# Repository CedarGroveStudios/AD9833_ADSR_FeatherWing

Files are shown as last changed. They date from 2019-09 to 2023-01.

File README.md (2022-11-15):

# MOVED TO: CedarGroveStudios/PCB_AD9833_ADSR_FeatherWing
https://github.com/CedarGroveStudios/PCB_AD9833_ADSR_FeatherWing.git

# This repo will be retired 2022-12-01

# AD9833_ADSR_FeatherWing
### _An amplitude-controlled version of the original AD9833 Waveform Generator FeatherWing_

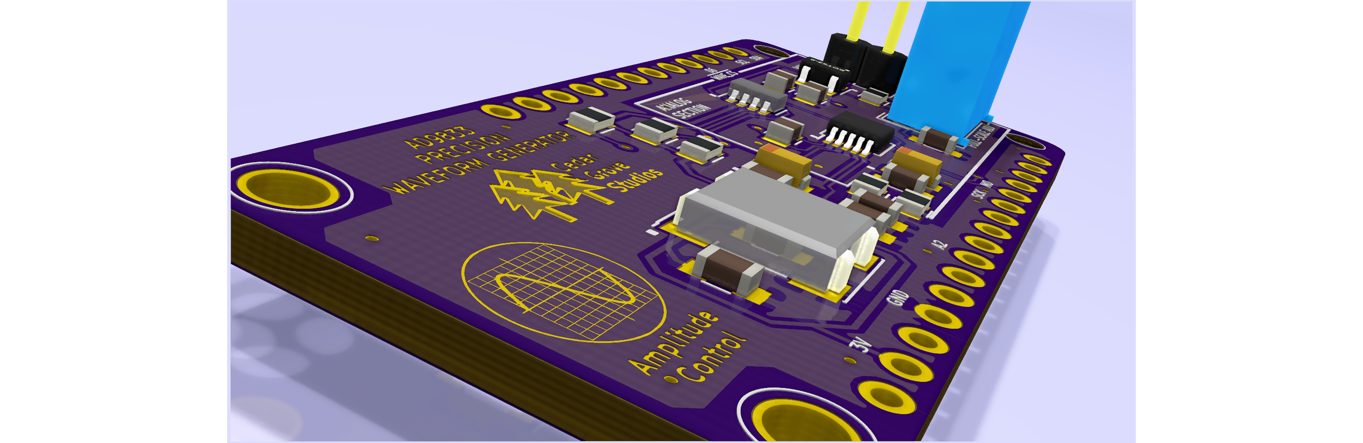
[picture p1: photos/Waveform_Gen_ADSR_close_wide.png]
Image of FeatherWing


## Overview
The AD9833 ADSR FeatherWing project is a software and hardware extension of previous work done on the AD9833 Waveform Generator FeatherWing. The ADSR project adds output amplitude control to simulate the Attack-Decay-Sustain-Release envelope needed to simulate musical instrument sounds.
The AD9833 ADSR FeatherWing is an Adafruit Feather-compatible module. The Waveform Generator portion, controlled by SPI, produces an op-amp buffered sine, triangle, or square wave output with a practical frequency range of 0.5Hz to 100KHz with 0.1Hz resolution. The on-board AD5245 Digital Potentiometer is a 256-step 10K potentiometer controlled by I2C. This PCB version includes enhanced power supply noise reduction and an improved output buffer amplifier with higher gain-bandwidth product.

Example MIDI synthesizer and sweep generator code is provided in the repository (sweep example video: https://youtu.be/O1vMfLoCWzg). 
MIDI synthesizer and sweep generator code was tested with a Feather M4 Express using CircuitPython version 4.1.0 rc-1.

MIDI note input was received by a Classic MIDI Interface FeatherWing from a variety of MIDI sources. See https://github.com/CedarGroveStudios/Classic_MIDI_FeatherWing for details.

OSH Park shared PCB project: https://oshpark.com/shared_projects/nDZsxzWR

## AD5245 Digital Potentiometer for Envelope Control
Unlike using the Feather's internal DAC as a multiplying DAC by applying a waveform to the DAC's reference voltage input, the digital potentiometer doesn't require a reference bias, eliminating the distortion that happens when the DAC's reference voltage is less than about 1v. The digital potentiometer's internal MOSFET switches are biased differently than a DAC, allowing the AD5245 potentiometer to control voltage values between ground and Vcc.

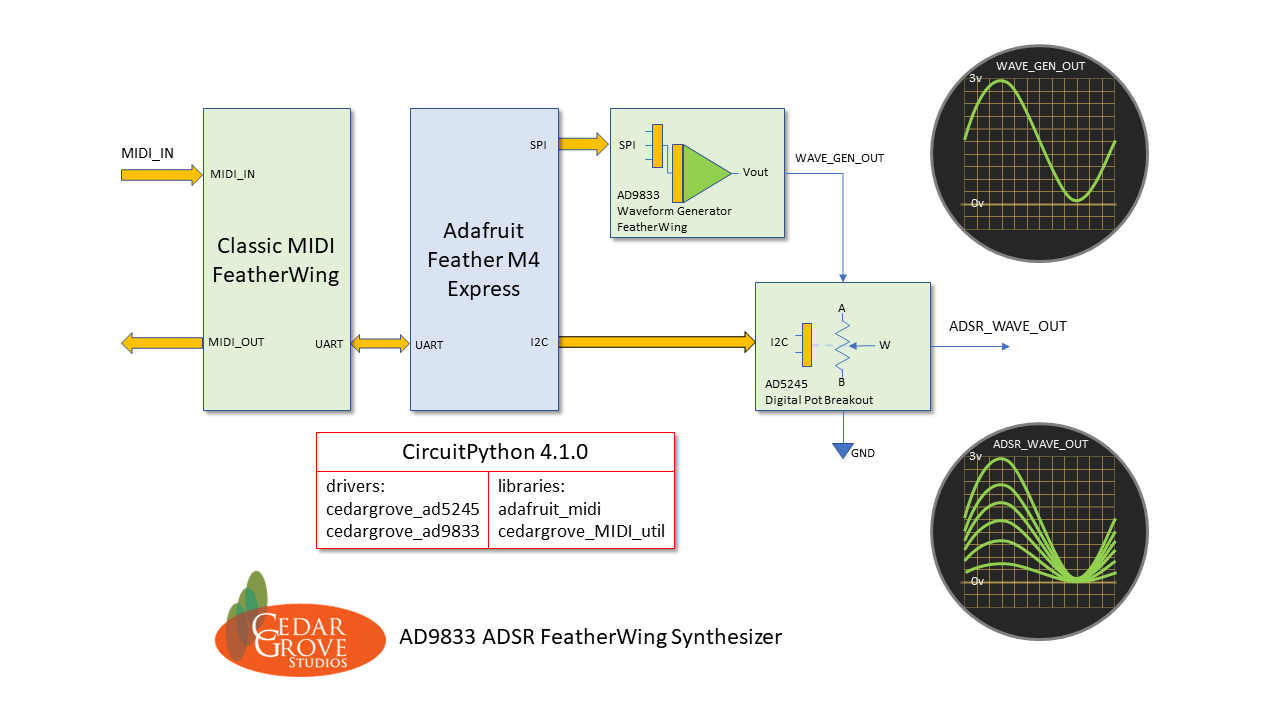
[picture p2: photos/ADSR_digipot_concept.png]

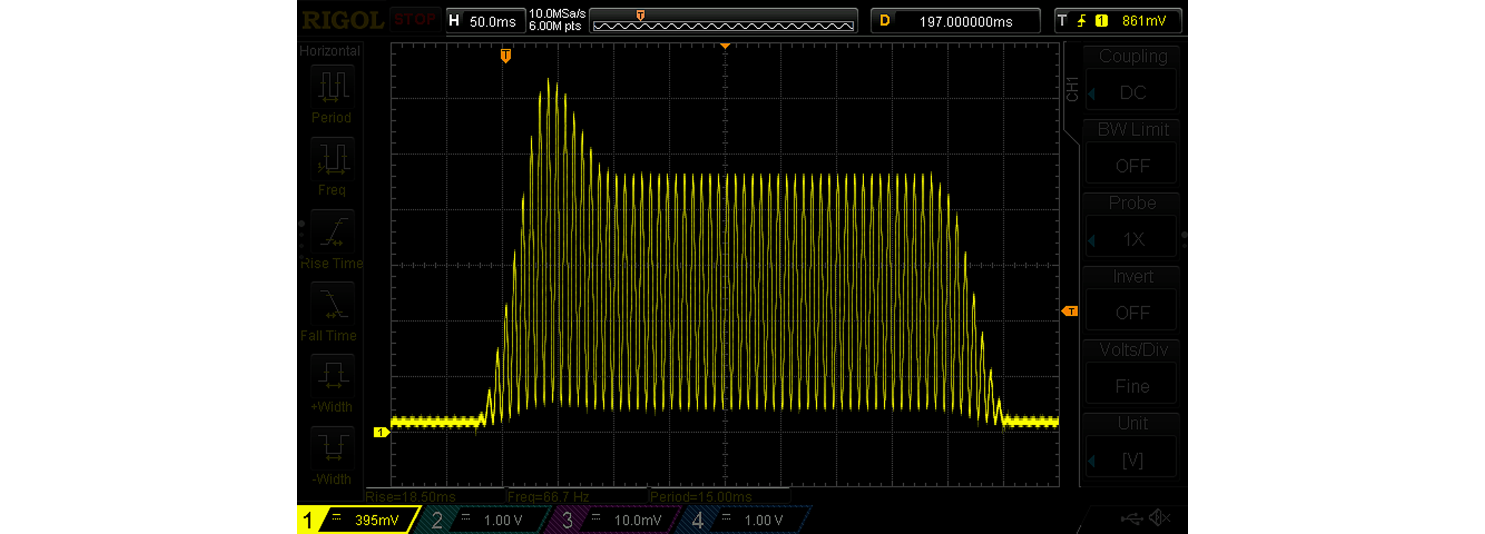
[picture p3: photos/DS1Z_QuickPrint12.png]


The resulting envelope met the original design expectations for distortionless scaling of the waveform's amplitude. The only issue faced was limited I2C data transfer rates during short-duration envelope segments such as shown during the Sustain segment below.

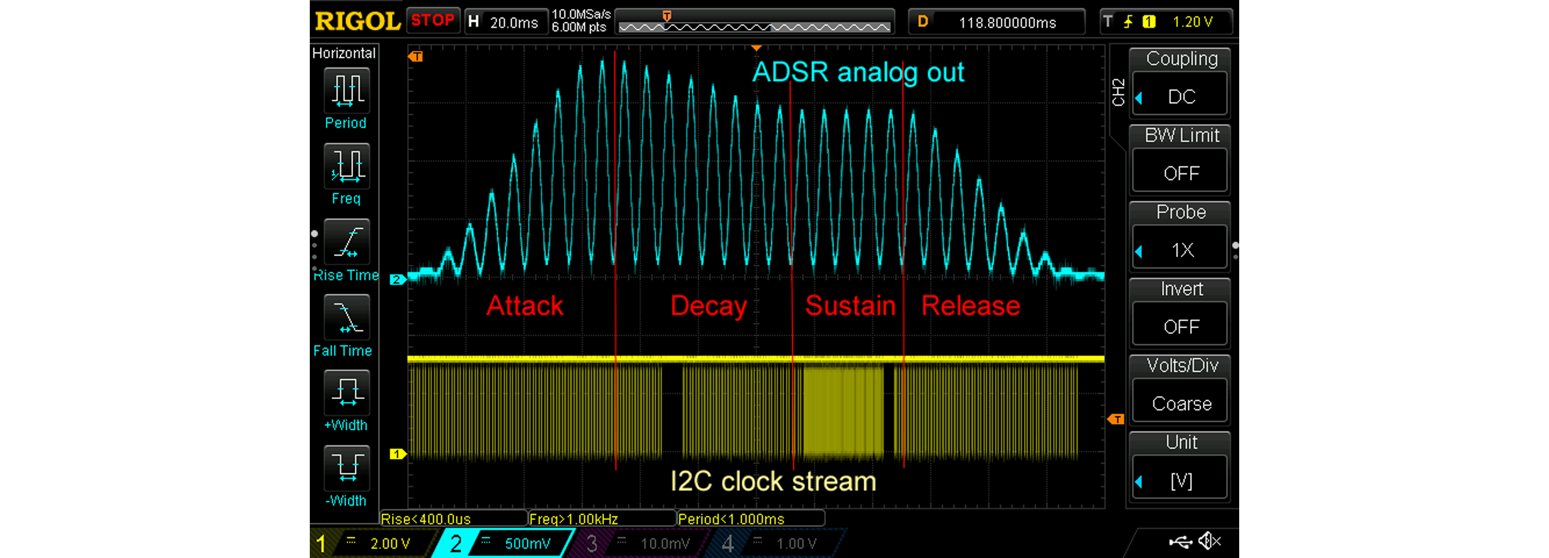
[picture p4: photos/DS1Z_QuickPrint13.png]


The latest version of the envelope segment control algorithm was modified to use a fixed time interval approach rather than a variable time interval based on segment duration. In the newest code, the digital potentiometer updates regularly every 1ms during segment generation, a speed easily accommodated by CircuitPython and the Feather M4 Express.

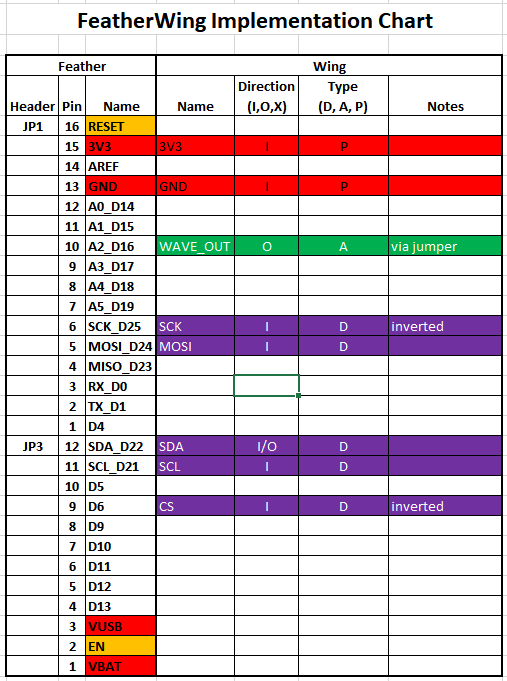
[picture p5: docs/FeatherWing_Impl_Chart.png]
FeatherWing Implementation Chart


## Primary Project Objectives
1)	Generate a smooth ADSR modulated waveform from the AD9833 across the audio spectrum (1Hz to 20KHz).  
2)	Implement with CircuitPython code.
3)  Develop CircuitPython libraries for the AD9833 and AD5245.
4)  Improve output bandwidth.
5)  Reduce power supply noise bleedthrough.
## Deliverables
1)	CircuitPython test, example, and library code
2)  Updated custom FeatherWing PCB  
  a) FeatherWing Implementation Chart  
  b) KiCAD schematic and board layout with Gerber code  
3)	OSH Park public shared project page
4)	GitHub public repository page
5)	Project description and report
## Concepts Learned
1)  The digital potentiometer approach is very viable and eliminates the multiplying DAC reference input bias distortion issue. 
2)  The digital potentiometer's 256-step resolution appears to be sufficient for artifactless envelope generation.
## Next Steps
  * Create a version of the PCB for the low-power AD9837 device (thanks to @jeffwurz).
  * Design a Eurorack-compatible version that provides MIDI and CV/Gate inputs.
  * Design a desktop test equipment version with display and selector knob.
  *	Incorporate the knowledge and experience gained in this project into the design of an Arbitrary Waveform Generator FeatherWing.

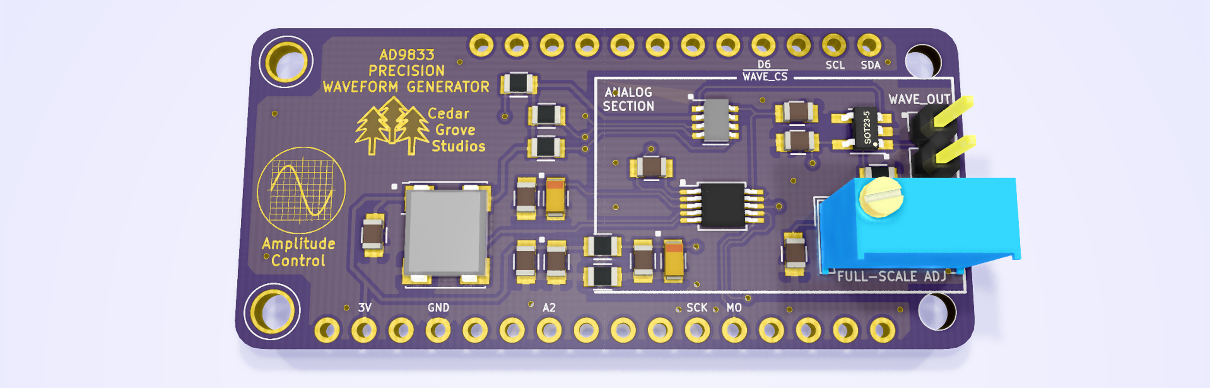
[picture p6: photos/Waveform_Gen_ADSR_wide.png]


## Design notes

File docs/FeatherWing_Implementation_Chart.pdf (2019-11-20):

Feather | Wing
Header | Pin | Name | Name | Direction (I,O,X) | Type (D, A, P) | Notes
JP1 | 16 | RESET
| 15 | 3V3 | 3V3 | I | P
| 14 AREF
| 13 | GND | GND | I | P
| 12 A0_D14
| 11 A1_D15
| 10 | A2_D16 | WAVE_OUT | O | A | via jumper
| 9 A3_D17
| 8 A4_D18
| 7 A5_D19
| 6 | SCK_D25 | SCK | I | D | inverted
| 5 | MOSI_D24 | MOSI | I | D
| 4 MISO_D23
| 3 RX_D0
| 2 TX_D1
| 1 D4
JP3 | 12 | SDA_D22 | SDA | I/O | D
| 11 | SCL_D21 | SCL | I | D
| 10 D5
| 9 | D6 | CS | I | D | inverted
| 8 D9
| 7 D10
| 6 D11
| 5 D12
| 4 D13
| 3 VUSB
| 2 EN
| 1 VBAT

## FeatherWing Implementation Chart

11/20/2019 12:01 AM FeatherWing_Implementation_Chart.xlsx FeatherWing Impl Chart | Page 1 of 1

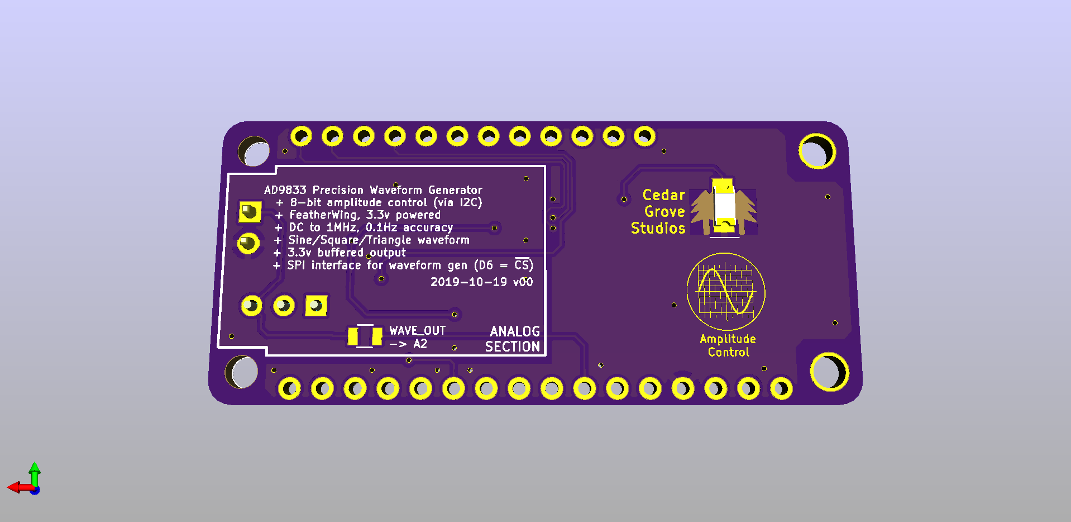
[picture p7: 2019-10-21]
photos/Waveform_Gen_ADSR bot.png

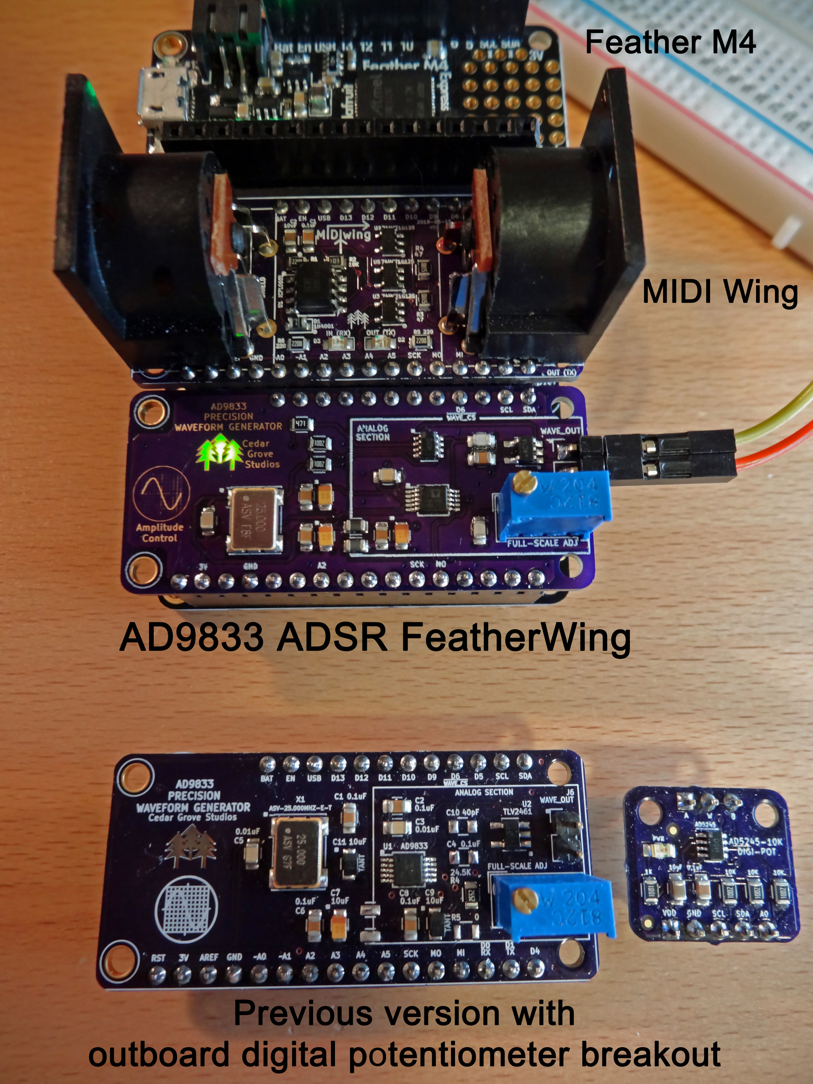
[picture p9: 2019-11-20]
photos/DSC05887anno_lores.jpg

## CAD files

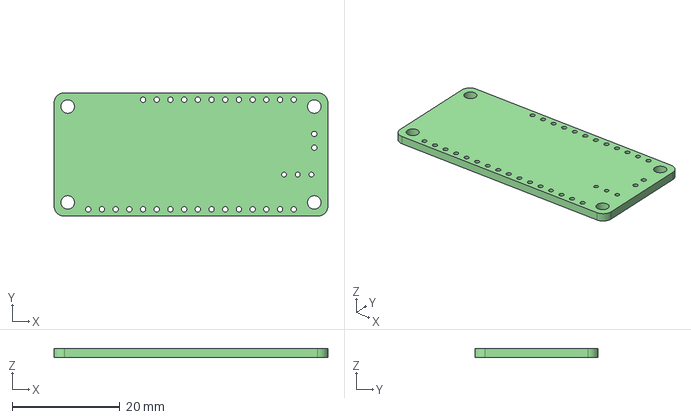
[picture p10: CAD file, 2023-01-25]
PCB/Waveform_Gen_ADSR.step
50.8 x 22.9 x 1.60 mm

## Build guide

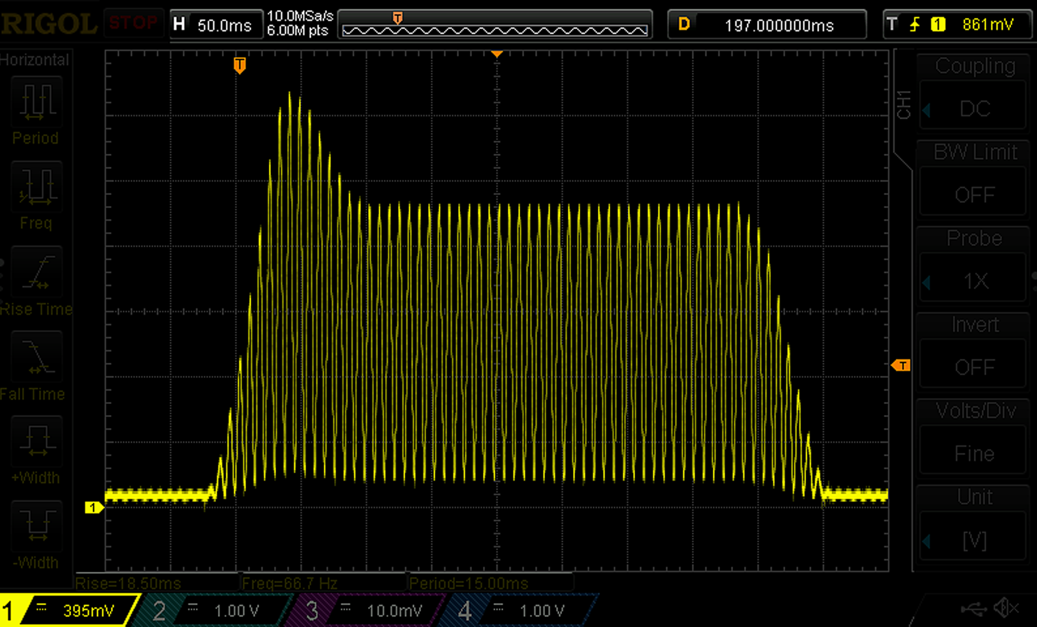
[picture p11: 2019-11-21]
photos/DS1Z_QuickPrint12_nar.png

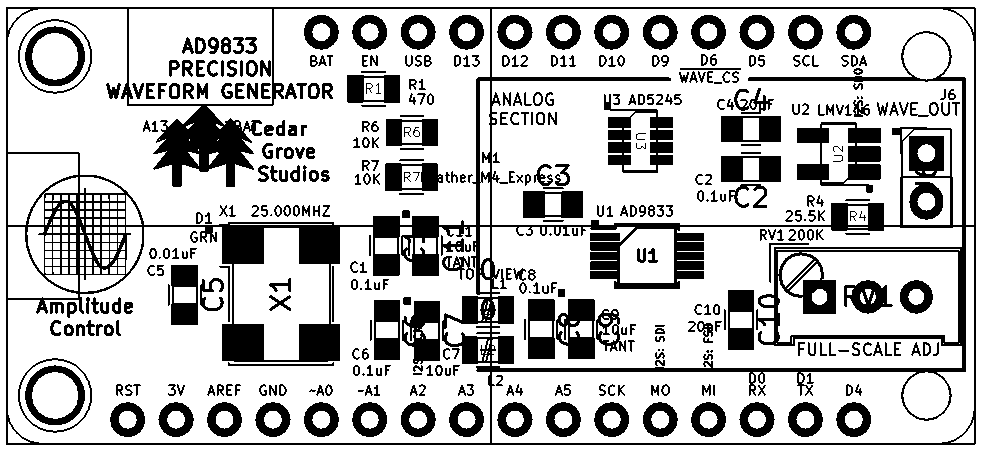
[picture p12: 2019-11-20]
photos/PCB_layout_guide.png

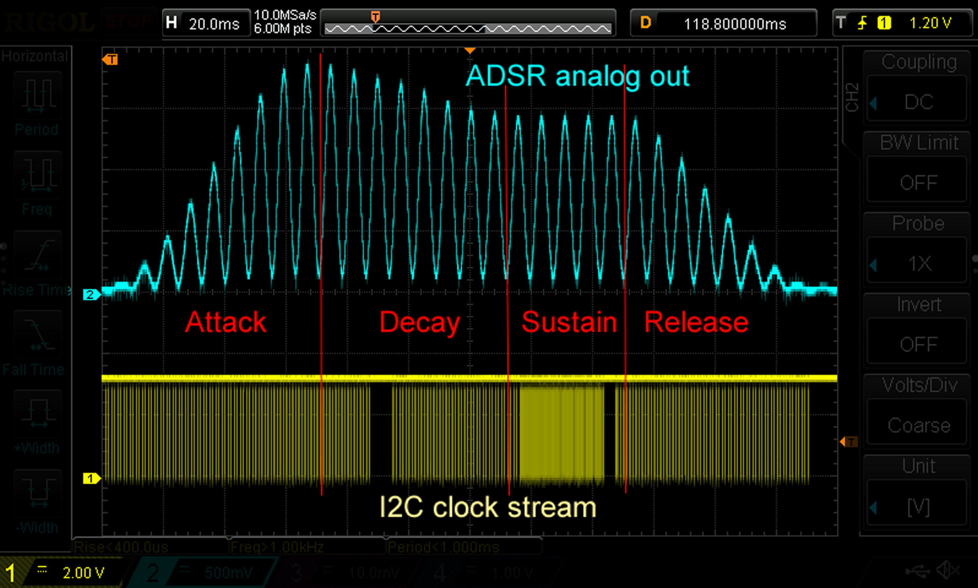
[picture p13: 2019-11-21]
photos/DS1Z_QuickPrint13_nar.png

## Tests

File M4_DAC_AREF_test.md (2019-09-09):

### _ADSR Envelope Extension for the Precision Waveform Generator FeatherWing_
# AD9833_ADSR

## M4 DAC AREF Test
In normal operation, the A0 DAC will produce an output voltage that is a fraction of the DAC's reference voltage as present on the Feather's AREF pin. Since the AREF pin is directly connected to the Feather's +3V power (nominally 3.3 volts), the DAC output is a fraction of the +3V supply voltage. Fortunately, the copper trace that connects AREF to 3V was designed to be removed, allowing other reference voltages to be substituted for +3V.

After the trace was removed, the 0v to +3v output of the waveform generator was connected to the AREF pin. The DAC reduced the voltage of the waveform generator, providing a variable amplitude based on the DAC digital input value. The ADSR envelope was generated by manipulating the DAC value in the CircuitPython code.

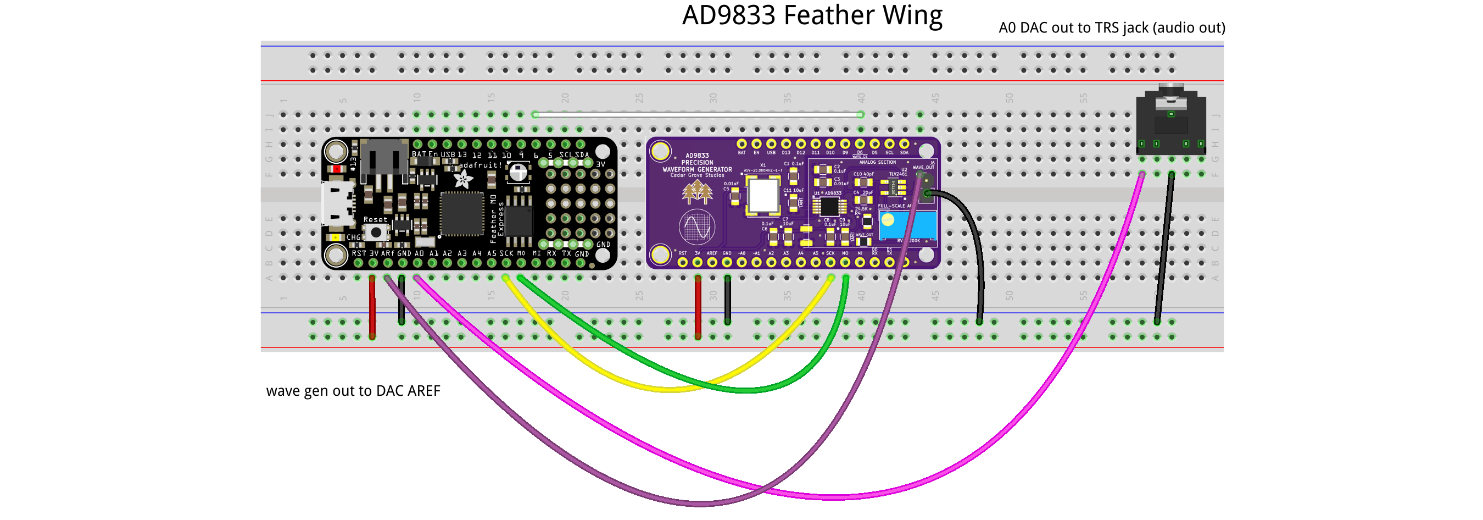
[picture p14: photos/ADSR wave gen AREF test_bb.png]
Image of AREF Test


The signal distortion caused by the AREF minimum bias voltage value (~1v) is clearly shown below. However, the test proved that the M4's on-board DAC can be successfully used to control AREF signal amplitude as long as the AREF signal voltage is between Vcc and +1v. 

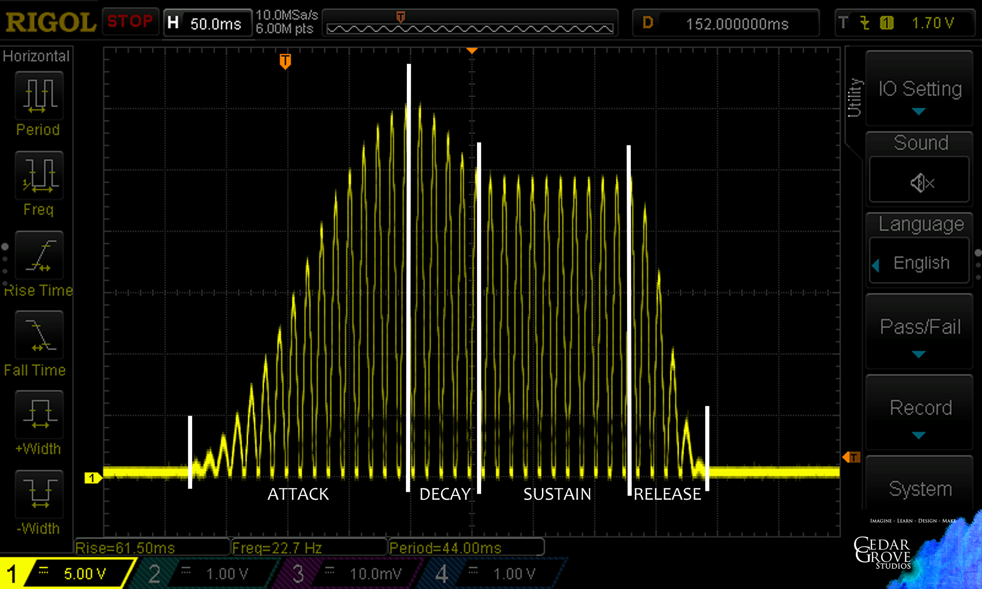
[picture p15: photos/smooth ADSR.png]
Test Results


### WARNING:  Remove the trace between 3V and AREF on the Feather board before attaching anything to the AREF pin. Don't connect any voltage to the AREF pin greater than the 3V provided by the Feather or lower than 0V (no negative voltage).

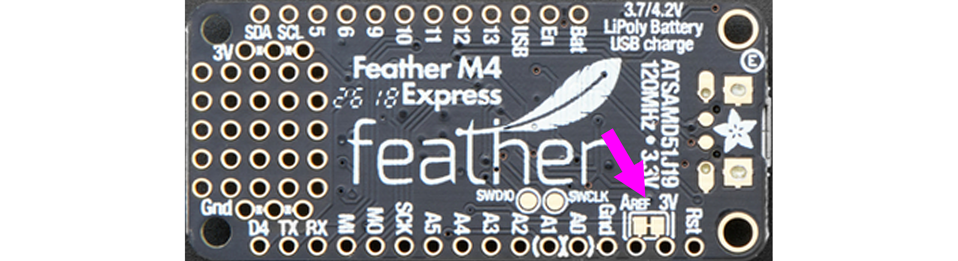
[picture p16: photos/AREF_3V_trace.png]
Image of AREF/3V Trace


## Concepts Learned
1)	It's possible to modulate the wave generator's output using the Feather M4 Express DAC AREF input pin (cut the 3.3v trace first).
2)  The AREF pin requires a voltage bias of at least VCC (typically +3.3 volts) and no less than 1.0 volts, although it worked emperically down to 0.5 volts.
3)  The M4 DAC resolution is much greater than required to generate a sufficient ADSR envelope.
4)  Using the AREF pin only changed the DAC reference voltage, not the ADC.
5)  The reference voltage for both on-board DACs was supplied by the single AREF analog input pin essentially making the second DAC useless for other purposes.

## Project Ideas:
### A manual level control for the _CircuitPython audioio_ library using the AREF pin for both M4 DACs (stereo output). A logarithmic potentiometer may be preferred for audio applications.  

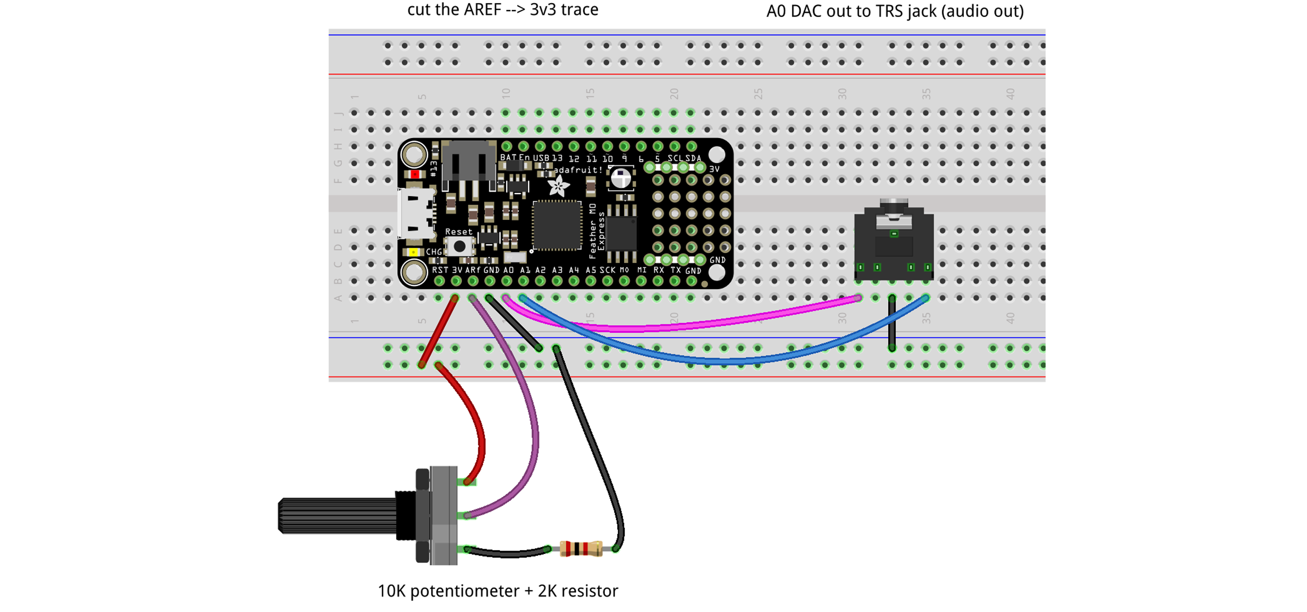
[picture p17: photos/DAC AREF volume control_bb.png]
Image of Manual AREF Level Control


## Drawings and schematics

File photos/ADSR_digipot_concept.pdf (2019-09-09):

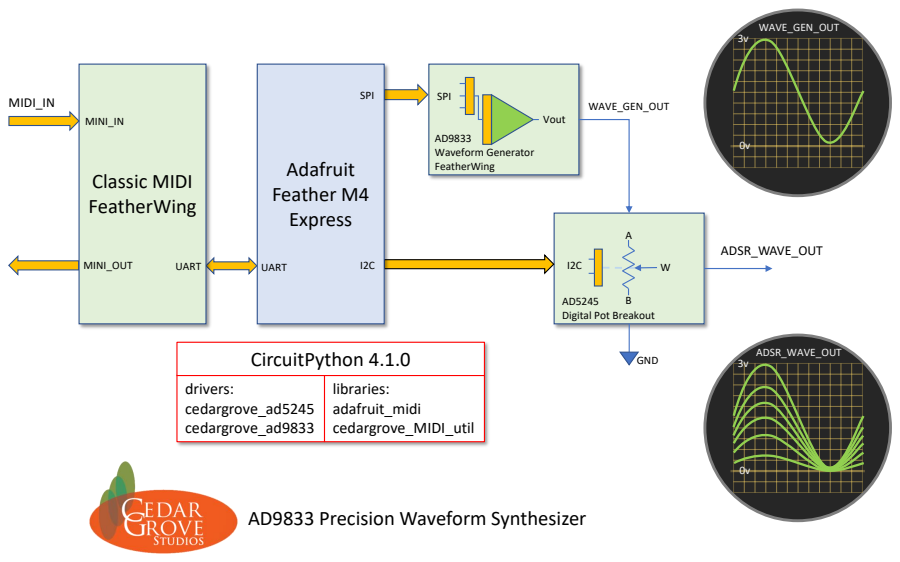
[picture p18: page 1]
AD9833 Waveform Generator FeatherWing; SPI; Vout; ADSR_WAVE_OUT; GND; WAVE_GEN_OUT; Adafruit Feather M4 Express; Classic MIDI FeatherWing; UART; MINI_IN; MIDI_IN; drivers: cedargrove_ad5245 cedargrove_ad9833; libraries: adafruit_midi cedargrove_MIDI_util; CircuitPython 4.1.0; MINI_OUT

Digital Pot Breakout

AD9833 Precision Waveform Synthesizer

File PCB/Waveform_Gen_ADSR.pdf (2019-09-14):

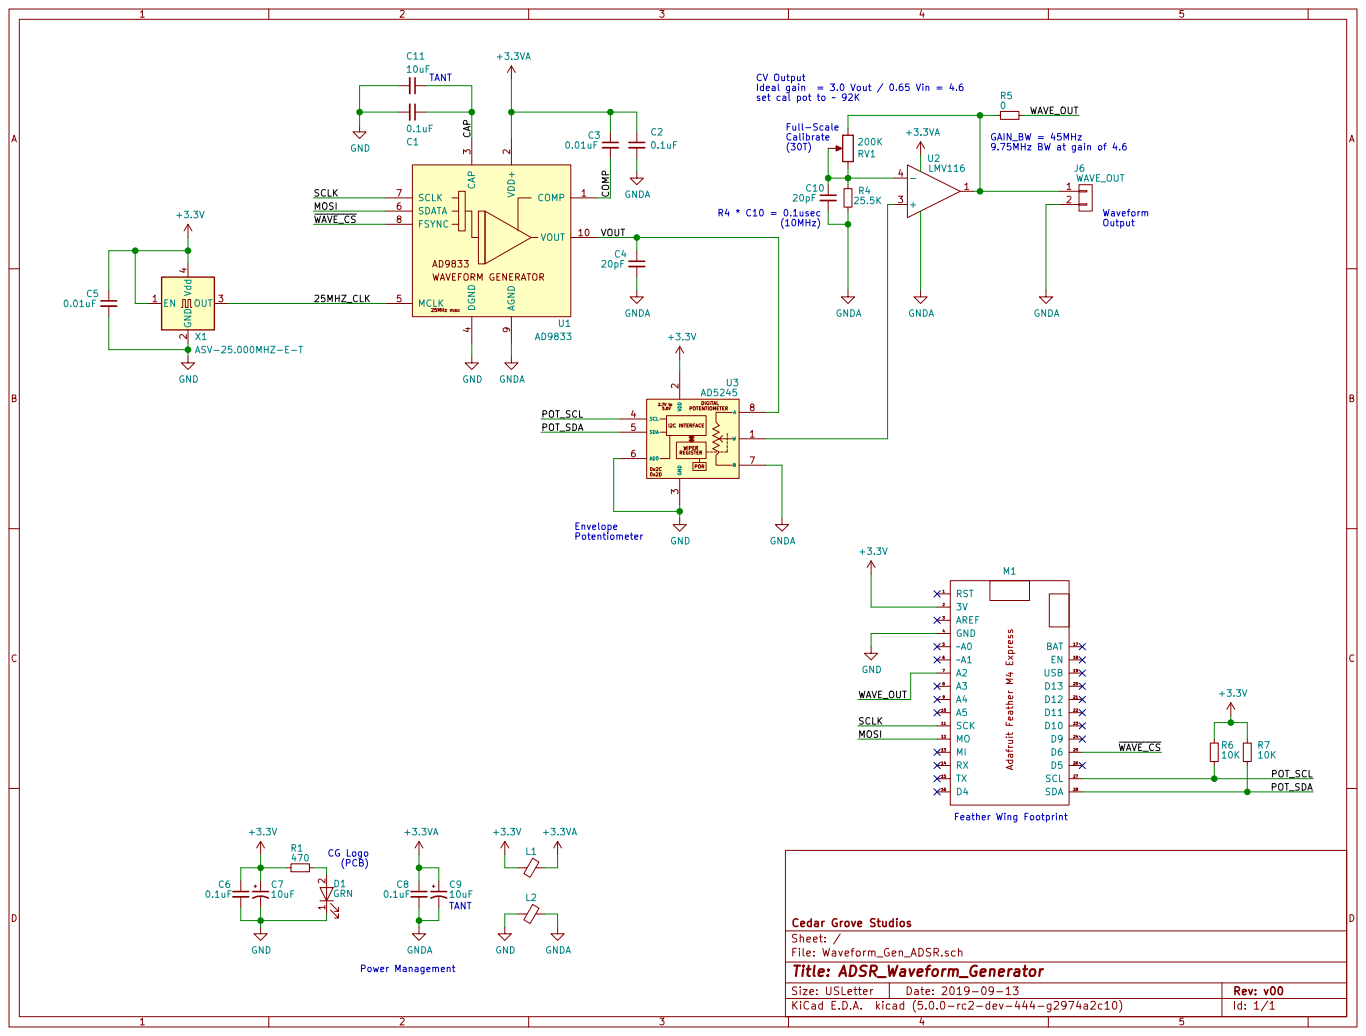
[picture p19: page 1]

CV Output
Ideal gain = 3.0 Vout / 0.65 Vin = 4.6
set cal pot to 92K

9U1 AD9833 Adafruit Feather M4 Express RST 1 A5 10 SCK 11 MO 12 MI 13 RX 14 TX 15 D4 16 BAT 17 EN 18 USB 19 3V 2 D13 20 D12 21 D11 22 D10 23 D9 24 D6 25 D5 26 SCL 27 SDA 28 AREF 3 GND 4 A0 5 A1 6 A2 7 A3 8 A4 9 M1 SCLK MOSI WAVE_CS

4 MCLK 5 SDATA 6 SCLK 7 FSYNC 8 AGND

File: Waveform_Gen_ADSR.sch Sheet: / Cedar Grove Studios GND

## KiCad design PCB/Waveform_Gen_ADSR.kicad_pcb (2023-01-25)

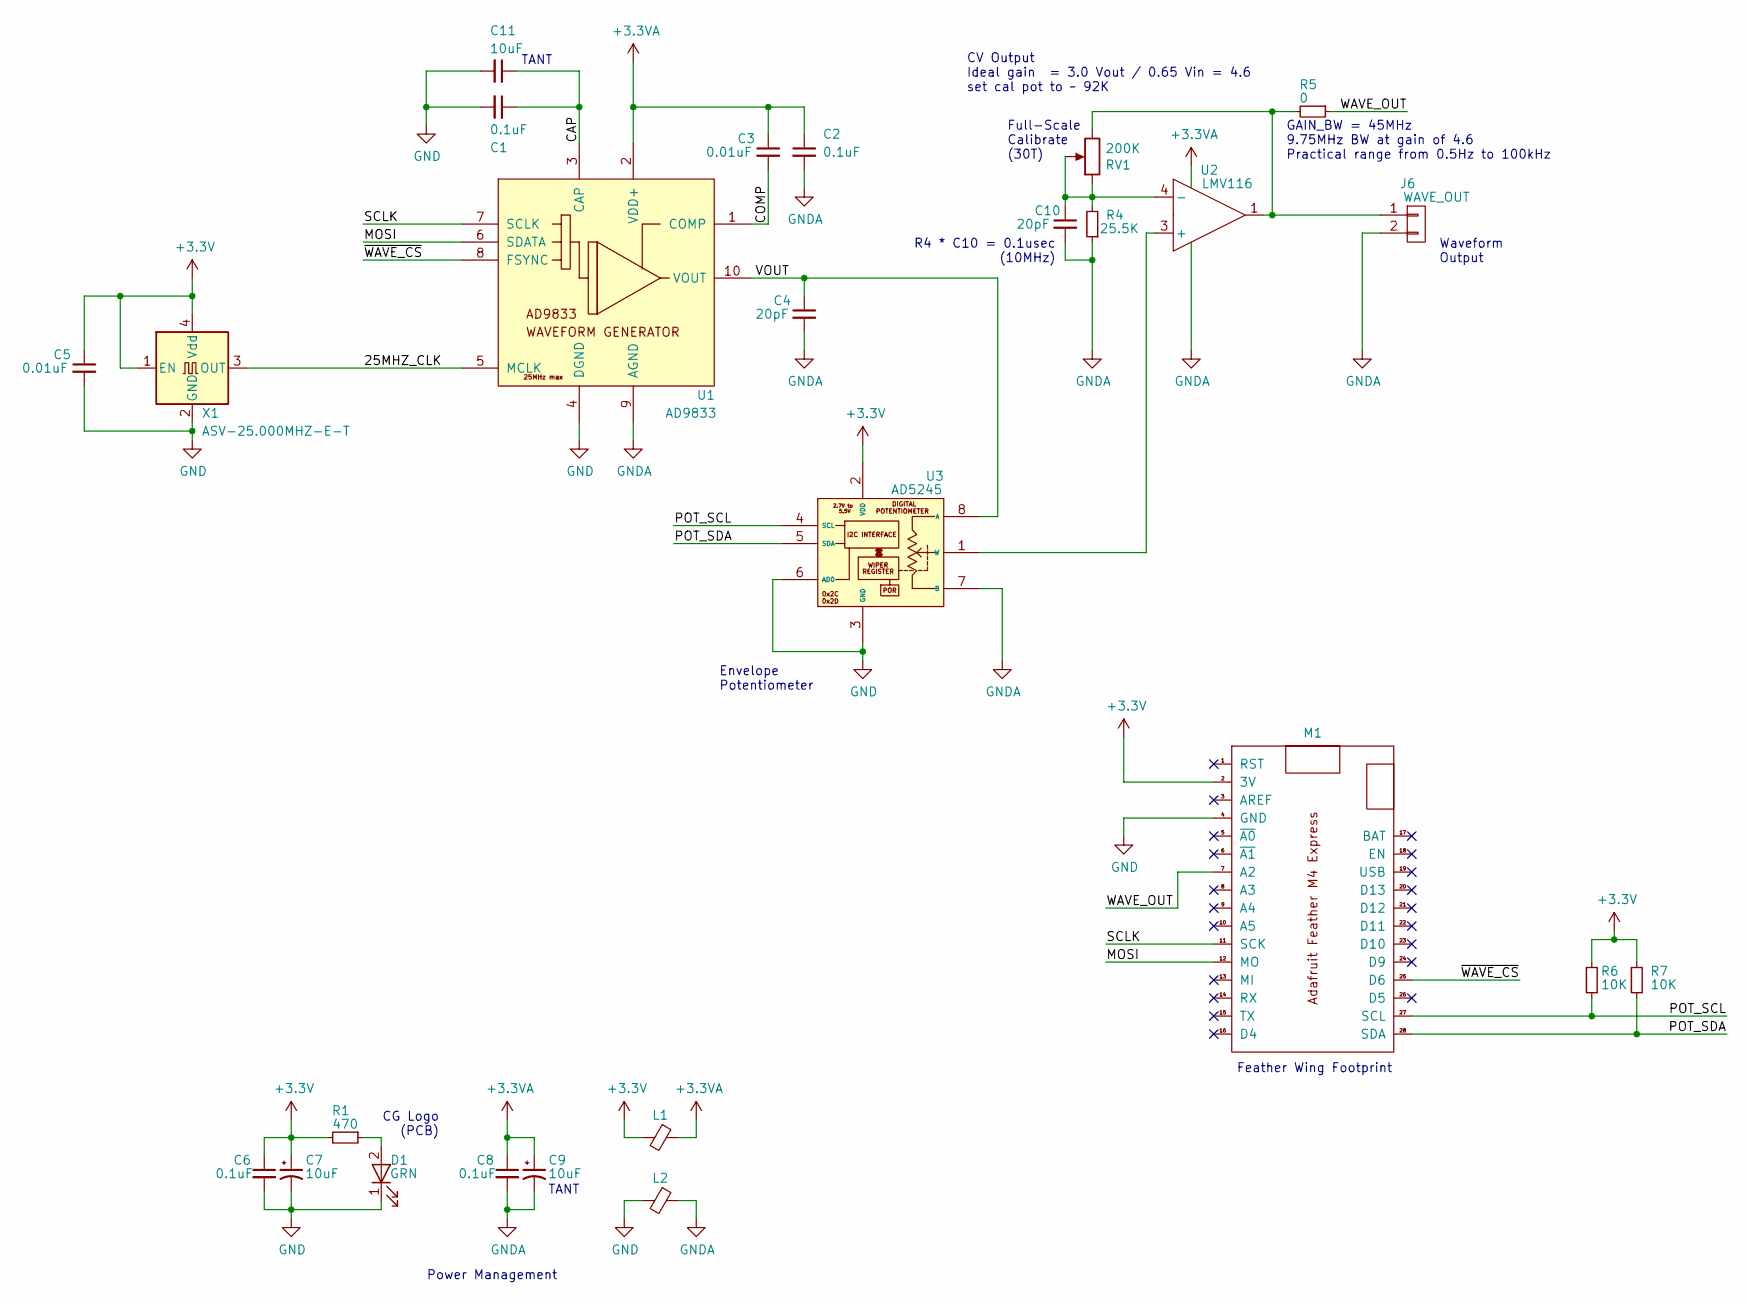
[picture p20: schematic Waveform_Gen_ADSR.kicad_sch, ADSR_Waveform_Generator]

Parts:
C1, C2, C6, C8: 0.1uF; C_0805
C3, C5: 0.01uF; C_0805
C4, C10: 20pF; C_0805
C7, C9, C11: 10uF; C_0805
D1: GRN; Cedar_Grove_logo_lighted
J6: WAVE_OUT; Pin_Header_Straight_1x02_Pitch2.54mm
L1, L2: 0; L_0805
M1: Feather_M4_Express; Adafruit_Feather_M4_Express_bare
R1: 470; R_0805
R4: 25.5K; R_0805
R5: 0; R_0805
R6, R7: 10K; R_0805
RV1: 200K; Potentiometer_Trimmer_Bourns_PV36W
U1: AD9833; MSOP-10_3x3mm_Pitch0.5mm
U2: LMV116; SOT-23-5_HandSoldering
U3: AD5245; SOT-23-8
X1: ASV-25.000MHZ-E-T; Oscillator_SMD_Abracon_ASV-4pin_7.0x5.1mm

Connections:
+3.3VA: C2.1, C3.1, C8.1, C9.1, L1.1, U1.2 (VDD+), U2.5 (VDD+)
+3V3: C5.1, C6.1, C7.1, L1.2, M1.2 (3V), R1.2, R6.2, R7.2, U3.2 (VDD), X1.1 (EN), X1.4 (Vdd)
/25MHZ_CLK: U1.5 (MCLK), X1.3 (OUT)
/CAP: C1.1, C11.1, U1.3 (CAP)
/COMP: C3.2, U1.1 (COMP)
/MOSI: M1.12 (MO), U1.6 (SDATA)
/POT_SCL: M1.27 (SCL), R6.1, U3.4 (SCL)
/POT_SDA: M1.28 (SDA), R7.1, U3.5 (SDA)
/SCLK: M1.11 (SCK), U1.7 (SCLK)
/VOUT: C4.1, U1.10 (VOUT), U3.8 (A)
/WAVE_OUT: M1.7 (A2), R5.1
/~WAVE_CS: M1.25 (D6), U1.8 (FSYNC)
GND: C1.2, C5.2, C6.2, C7.2, C11.2, D1.1 (K), L2.2, M1.4 (GND), U1.4 (DGND), U3.3 (GND), U3.6 (AD0), X1.2 (GND)
GNDA: C2.2, C4.2, C8.2, C9.2, C10.2, J6.2, L2.1, R4.1, U1.9 (AGND), U2.2 (VDD-), U3.7 (B)
unnamed: C10.1, R4.2, RV1.1, RV1.2, U2.4 (-)
unnamed: D1.2 (A), R1.1
unnamed: J6.1, R5.2, RV1.3, U2.1
unnamed: U2.3 (+), U3.1 (W)

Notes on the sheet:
GAIN_BW = 45MHz 9.75MHz BW at gain of 4.6 Practical range from 0.5Hz to 100kHz
TANT
CG Logo (PCB)
CV Output Ideal gain = 3.0 Vout / 0.65 Vin = 4.6 set cal pot to ~ 92K
R4 * C10 = 0.1usec (10MHz)
Full-Scale Calibrate (30T)
Power Management
Envelope Potentiometer
Waveform Output
Feather Wing Footprint

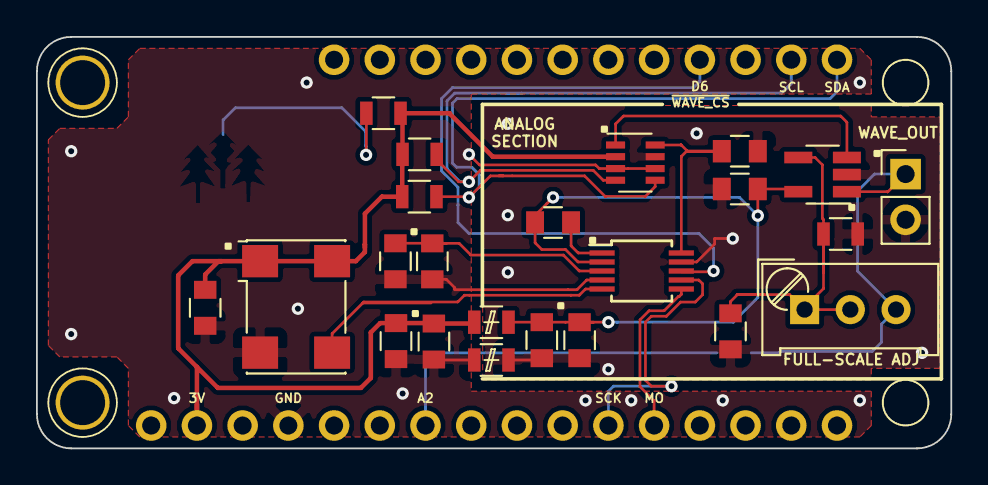
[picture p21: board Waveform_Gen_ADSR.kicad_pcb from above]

Board: 2 copper layers, 50.8 x 22.9 mm, 26 parts (1 on the bottom side), 18 nets.

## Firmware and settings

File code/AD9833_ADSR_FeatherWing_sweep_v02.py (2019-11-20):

# AD9833_ADSR_FeatherWing_sweep_v02.py
# 2019-11-19 Cedar Grove Studios
# Fixed or swept frequency generator example. Update "initial parameters"
# section for required functionality.
#
# uses cedargrove_ad9833 driver
# Tested with Adafruit Feather M4 Express and CircuitPython 4.1.0 rc-1.

import time
import cedargrove_ad5245
digi_pot = cedargrove_ad5245.AD5245(address=0x2C)
digi_pot.shutdown()  # mute the output before instantiating wave_gen

import cedargrove_ad9833
wave_gen = cedargrove_ad9833.AD9833(select='D6')


# *** Helpers ***

# *** Main code area ***
print("AD9833_ADSR_FeatherWing_sweep_v02.py")

# establish initial parameters
begin_freq =  20        # fixed or sweep starting frequency (Hz)
end_freq = 21000        # sweep ending frequency (Hz)
inc_freq = 10           # sweep freqency step size (Hz)
periods_per_step = 3    # number of waveform periods to hold (non-linear mode)
sweep_mode = "non-linear"    # fixed (10ms per step) or non-linear sweep hold timing
freq_mode = "sweep"     # fixed or sweep frequency
wave_type = "sine"      # sine, triangle, or square waveform
amplitude = 1.0         # normalized potentiometer value (0 to 1.0)

debug = True

if debug:
    print("begin:", begin_freq, "  end:", end_freq, "  incr:", inc_freq)
    print("periods per step:", periods_per_step)
    print("sweep mode:", sweep_mode, "  freq mode:", freq_mode, "  wave type:", wave_type)
    time.sleep(1)

while True:
    wave_gen.reset()
    wave_gen.wave_type = wave_type
    wave_gen.start()
    digi_pot.normalized_wiper = amplitude

    if freq_mode == "sweep":
        wave_gen.start()

        for i in range(begin_freq, end_freq, inc_freq):
            if debug: print("sweep: frequency =", i)
            wave_gen.update_freq(i)

            if sweep_mode == "non-linear":
                time.sleep(periods_per_step * (1 / i))  # pause for x periods at the specified frequency
            else:
                time.sleep(0.010)  # 10msec fixed hold time per step
    else:
        # output a fixed frequency for 10 seconds
        if debug: print("fixed: frequency =", begin_freq)
        wave_gen.update_freq(begin_freq)
        wave_gen.start()
        time.sleep(10)  # 10sec fixed hold time

    digi_pot.shutdown()  # mute the output
    wave_gen.stop()  # stop wave generator

    time.sleep(2)  # wait a second then do it all over again

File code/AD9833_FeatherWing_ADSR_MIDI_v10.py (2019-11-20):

# AD9833_FeatherWing_ADSR_MIDI_v10.py
# 2019-08-25 Cedar Grove Studios
# Simple MIDI voice module using Cedar Grove AD9833 Precision Waveform
#     Generator FeatherWing, Cedar Grove Classic MIDI FeatherWing, and
#     Cedar Grove AD5245 Digital Potentiometer Breakout
#
#      cedargrove_AD9833_FeatherWing library
#      cedargrove_MIDI_util library
#      cedargrove_AD5245 library
#
# Tested with Adafruit Feather M4 Express and CircuitPython 4.1.0 rc-1.

import cedargrove_ad5245
digi_pot = cedargrove_ad5245.AD5245(address=0x2C)
digi_pot.shutdown()  # mute the output before instantiating wave_gen

# establish class instance with chip_select pin D6
import cedargrove_AD9833_FeatherWing as AD9833
wave_gen = AD9833.WaveGenerator(select="D6")

import board
import busio
import time
from math import sin
import adafruit_midi
import usb_midi

from cedargrove_MIDI_util import *

from adafruit_midi.timing_clock            import TimingClock
from adafruit_midi.channel_pressure        import ChannelPressure
from adafruit_midi.control_change          import ControlChange
from adafruit_midi.note_off                import NoteOff
from adafruit_midi.note_on                 import NoteOn
from adafruit_midi.pitch_bend              import PitchBend
from adafruit_midi.polyphonic_key_pressure import PolyphonicKeyPressure
from adafruit_midi.program_change          import ProgramChange
from adafruit_midi.start                   import Start
from adafruit_midi.stop                    import Stop
from adafruit_midi.system_exclusive        import SystemExclusive
from adafruit_midi.midi_message            import MIDIUnknownEvent

UART = busio.UART(board.TX, board.RX, baudrate=31250, timeout=0.001)
midi = adafruit_midi.MIDI(midi_in=UART, midi_out=UART, in_channel=0, out_channel=0)

# *** Helpers ***

def amplitude_stepper(start, end, period, level=1.0, debug=False):  # step from start to end amplitude over time period
    step = 0.001  # step through segment in 1ms steps
    seg_time = 0
    if start < end:
        while seg_time <= period:
            angle = (3 / 2 * 3.14159) + ((3.14159 * (seg_time / period)))
            amplitude = (start + ((end - start) * ((sin(angle) + 1) / 2))) * level
            digi_pot.normalized_wiper = amplitude
            if debug: print((amplitude,))
            time.sleep(step)
            seg_time = seg_time + step
    elif start > end:
         while seg_time <= period:
            angle = (1 / 2 * 3.14159) + ((3.14159 * (seg_time / period)))
            amplitude = (end + ((start - end) * ((sin(angle) + 1) / 2))) * level
            digi_pot.normalized_wiper = amplitude
            if debug: print((amplitude,))
            time.sleep(step)
            seg_time = seg_time + step
    else:  # start = end
        while seg_time <= period:
            digi_pot.normalized_wiper = start * level
            if debug: print((start * level,))
            time.sleep(step)
            seg_time = seg_time + step

def wave_ADSr(a=(1.0,0), d=(1.0,0), s=(1.0,0), level=1.0):
    amplitude_stepper(0, a[0], a[1], level)  # attack
    amplitude_stepper(a[0], d[0], d[1], level)  # decay
    amplitude_stepper(d[0], s[0], s[1], level)  # sustain

def wave_adsR(s=(1.0,0), r=(0.0,0), level=1.0):
    amplitude_stepper(s[0], r[0], r[1], level)  # release

# *** Main code area ***
print("AD9833_FeatherWing_ADSR_MIDI_v10.py")
print("Input channel:", midi.in_channel + 1 )

# establish initial parameters
adsr_A  = (1.0, 0.090)  # attack level, period in seconds
adsr_D  = (0.8, 0.080)  # decay level, period in seconds
adsr_S  = (0.8, 0.002)  # sustain level, period in seconds
adsr_R  = (0.0, 0.080)  # release level, period in seconds

t0 = time.monotonic_ns()
tempo = 0.0  # establish initial tempo value
playing = []  # set up LIFO buffer for notes

wave_type = "sine"  # sine, triangle, or square waveform
wave_gen.reset()  # reset and stop the wave generator; reset all registers
wave_gen.wave_type = wave_type  # load the waveform type value
wave_gen.stop
digi_pot.shutdown()  # squelch output

while True:
    msg = midi.receive()

    if msg is not None:
        # midi.send(msg)  # MIDI thru
        if isinstance(msg, NoteOn):
            print("NoteOn : #%02d %s %5.3fHz" % (msg.note, note_lexo(msg.note), note_freq(msg.note)))
            print("     vel   %03d     chan #%02d" %(msg.velocity, msg.channel + 1))

            if msg.velocity == 0:  # some note wants to stop playing now
                if len(playing) != 0:
                    if msg.note == playing[-1][0]:  # stop playing the current note
                        wave_adsR(adsr_S, adsr_R, playing[-1][1] / 127)
                        digi_pot.shutdown()  # mute output
                        playing.pop()  # remove current note from the list
                    else:  # otherwise just remove it from the list so that it won't replay
                        for i in range(0, len(playing)):
                            if playing[i][0] == msg.note:
                                playing.remove(playing[i])
                                break
            else:
                if len(playing) != 0:
                    if msg.note != playing[-1][0]:  # another note wants to play over the top of current note
                        wave_adsR(adsr_S, adsr_R, playing[-1][1] / 127)  # release current note
                        digi_pot.shutdown()  # mute output
                        playing.pop()  # remove current note from the list

                wave_gen.update_freq(note_freq(msg.note))  # set frequency register and play new note
                wave_gen.start()  # start oscillator
                wave_ADSr(adsr_A, adsr_D, adsr_S, msg.velocity / 127)
                playing.append((msg.note, msg.velocity))  # add new note to the playing list

        elif isinstance(msg, NoteOff):
            print("NoteOff: #%02d %s %5.3fHz" % (msg.note, note_lexo(msg.note), note_freq(msg.note)))
            print("     vel   %03d     chan #%02d" %(msg.velocity, msg.channel + 1))
            if len(playing) != 0:
                if msg.note == playing[-1][0]:  # stop playing the current note
                    wave_adsR(adsr_S, adsr_R, playing[-1][1] / 127)
                    digi_pot.shutdown()  # mute output
                    playing.pop()  # remove current note from the list
                else:  # otherwise just remove it from the list so that it won't replay
                    for i in range(0, len(playing)):
                        if playing[i][0] == msg.note:
                            playing.remove(playing[i])
                            break

        elif isinstance(msg, TimingClock):
            t1 = time.monotonic_ns()
            if (t1-t0) != 0:
                tempo = (tempo + (1 / ((t1 - t0) * 24) * 60 * 1e9)) / 2 # simple running average
                # print("-- Tick: %03.1f BPM" % tempo)  # compared to previous tick
            t0 = time.monotonic_ns()
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

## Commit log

2019-09-09 update version number
    [Waveform_Gen_ADSR.kicad_pcb, Waveform_Gen_ADSR.sch]
2019-09-09 working on layout
    [Waveform_Gen_ADSR.kicad_pcb, Waveform_Gen_ADSR.sch]
2019-09-10 update layout
    [Waveform_Gen_ADSR.kicad_pcb]
2019-09-10 update PCB layout
    [Waveform_Gen_ADSR.kicad_pcb, Waveform_Gen_ADSR.sch]
2019-09-11 update layout; stack AD983x footprints
    [Waveform_Gen_ADSR.kicad_pcb, Waveform_Gen_ADSR.sch]
2019-09-11 update pcb layout; add stacked footprints; add sine logo
    [Waveform_Gen_ADSR.kicad_pcb]
2019-09-12 update PCB layout; include support for AD9837
    [Waveform_Gen_ADSR.kicad_pcb, Waveform_Gen_ADSR.sch]
2019-09-14 change scope to support only AD9833
    [Waveform_Gen_ADSR-B.Cu.gbl, Waveform_Gen_ADSR-B.Mask.gbs, Waveform_Gen_ADSR-B.Paste.gbp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]
2019-11-20 update photos and board design files
    [Waveform_Gen_ADSR-B.Cu.gbl, Waveform_Gen_ADSR-B.Mask.gbs, Waveform_Gen_ADSR-B.SilkS.gbo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]
2019-11-20 update FeatherWing Implementation Chart
    [FeatherWing_Implementation_Chart.xlsx]
2021-07-12 update documents
    [FeatherWing_Implementation_Chart.xlsx, Waveform_Generator_BOM.xlsx]
2022-07-01 update kicad tables
2022-10-12 move code to CircuitPython_AD5245
2022-11-15 Repository is moving to PCB_AD9833_ADSR_FeatherWing
2023-01-13 update kicad backup
2023-01-18 update footprints; 3d images
    [Waveform_Gen_ADSR.step]
2023-01-25 update backup folder
    [Waveform_Gen_ADSR.kicad_pcb, Waveform_Gen_ADSR.step]
2023-01-31 update backups
    [Waveform_Gen_ADSR.kicad_sch]
